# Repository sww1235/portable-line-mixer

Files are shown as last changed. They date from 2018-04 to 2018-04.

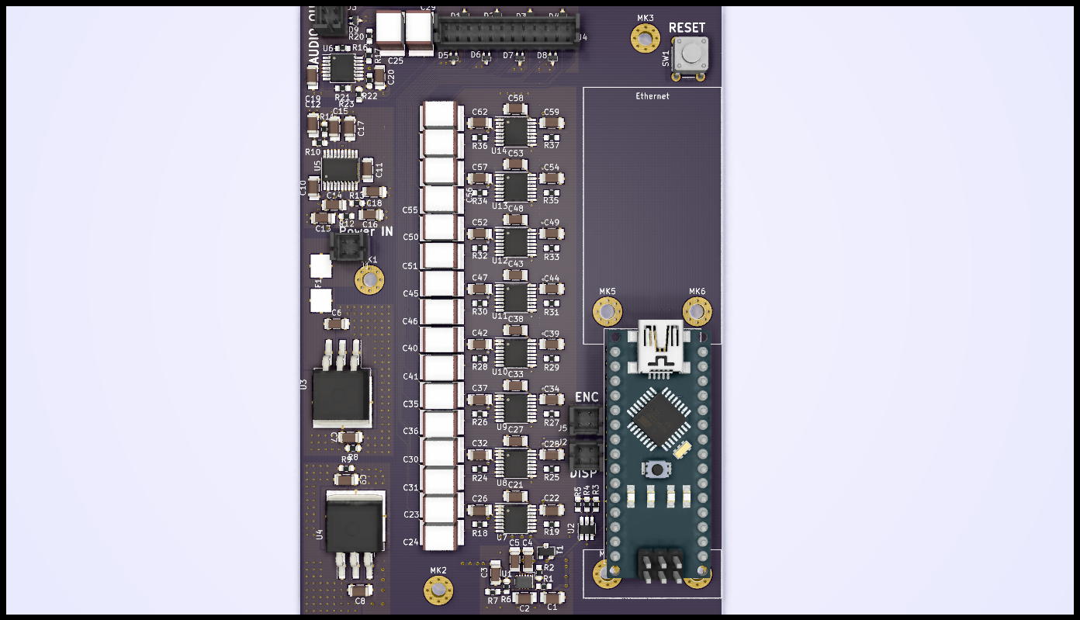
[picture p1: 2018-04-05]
portable-line-mixer.png

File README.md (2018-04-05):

# portable-line-mixer
A compact line level audio mixer.

Volume control via Digipots.

## TODO

-   Export BOM and price out parts
-   CODE

## Extra parts

-   772-E25-103RYY1 norcomp db25 IP67 connector male
-   772-E25-203RYY1 norcomp db25 IP67 connector female (for panelmount)
-   967-025-010R011 norcomp db25 IP67 backshell for cable
-   SFP6725 norcomp adhesive seal db25 size
-   967-025-CAP norcomp ip67 sealing cap
-   160-067-004R034 norcomp db25 hardware kit
-   767KS1(X) 0.084 \[2.1\] id/od sealed locking power plug switchcraft
-   L722AS 0.08 \[2.0\] id/od sealed locking power jack switchcraft (these sizes are compatible with high amperage version)
-   JCAP  power jack cover
-   35FM3AULS - Sealed locking 3.5mm panel mount jack switchcraft
-   35HDLBAU(S) 3.5mm sealed locking plug switchcraft (S=0.175 diameter cable, no S=0.29 diameter cable)
-   NE8FDX-P6-W IP rated ethercon connector Cat6A shielded neutrik
-   NE8MX6 Cat6A ethercon cable connector neutrik

## Max Power Consumption figures

| Component | Quantity | Current  | Voltage | Total Watts |
|:---|:---|:---|:---|:---|
| 4x Op Amp | 1 | 2.8mA | ±12V | 67.2mW |
| digipots  | 8 | 2uA, 5uA | +5VD, ±5VA | 0.48mW -> 0.5mW |
| microproc | 1 | 27mA | 5V | 135mW |
| Total | | | | 202.68mW |
| ref total | | | | 500mW |

## References / sources

### Code
-   <http://playground.arduino.cc/Main/RotaryEncoders#Example1>
-   <https://www.arduino.cc/en/Reference/Wire>
-   <http://gammon.com.au/interrupts>
-   <https://www.arduino.cc/en/Reference/AttachInterrupt>

### Physical Design
-   <https://m.reddit.com/r/arduino/comments/1tr7in/question_i_burned_out_this_small_smd_component_on/>
-   <https://www.arduino.cc/en/Hacking/PinMapping32u4>
-   <https://www.arduino.cc/en/Main/ArduinoBoardMicro>
-   <http://www.atmel.com/Images/Atmel-7766-8-bit-AVR-ATmega16U4-32U4_Datasheet.pdf>
-   <http://sound.whsites.net/articles/capacitors.htm>
-   <http://electronics.stackexchange.com/questions/210376/details-on-pcb-layout-for-microcontroller>
-   <http://electronics.stackexchange.com/questions/210580/pcb-microcontroller-layout-in-a-mixed-signal-system>
-   <http://electronics.stackexchange.com/questions/7535/what-precautions-should-i-take-when-mixing-analog-audio-and-digital-on-the-same>
-   <https://wiki.xtronics.com/index.php/Eeschema#Printing_to_a_web_viewable_file>
-   <http://www.all-electric.com/schematic/simp_mix.htm>
-   <http://sound.whsites.net/articles/audio-mixing.htm>
-   <http://www.hobbyprojects.com/A/mixers.html>
-   <https://www.maximintegrated.com/en/app-notes/index.mvp/id/1133>
-   <https://books.google.com/books?id=rZDbnQ0siCYC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>
-   <http://electronics.stackexchange.com/questions/5403/standard-pcb-trace-widths>
-   <http://electronics.stackexchange.com/questions/185212/i2c-pcb-layout-considerations>
-   <http://electronics.stackexchange.com/questions/39136/competing-pcb-crystal-layout-recommendations>
-   <http://electronics.stackexchange.com/questions/41851/how-critical-is-the-layout-of-usb-data-lines-how-does-my-layout-look>
-   <http://www.atmel.com/Images/Atmel-8128-Best-Practices-for-the-PCB-Layout-of-Oscillators_ApplicationNote_AVR186.pdf>
-   <http://www.ti.com/lit/an/scaa082/scaa082.pdf>
-   <http://electronics.stackexchange.com/questions/15135/decoupling-caps-pcb-layout/>
-   <http://electronics.stackexchange.com/questions/117817/learning-pcb-layout-strategy>
-   <http://electronics.stackexchange.com/questions/216410/pcb-layout-needs-improvement>
-   <http://electronics.stackexchange.com/questions/28251/rules-and-guidelines-for-drawing-good-schematics>
-   <http://electronics.stackexchange.com/questions/20180/pcb-layout-questions-for-mcu-breakout-board>
-   <http://electronics.stackexchange.com/questions/19688/is-it-normal-to-have-a-rats-nest-of-vcc-gnd-traces-under-an-ic>
-   <http://www.onmyphd.com/?p=pcb.design>
-   <http://www.ti.com/lit/an/scaa048/scaa048.pdf>
-   <http://www.hottconsultants.com/questions/mixed-signal_PCB_layout.html>
-   <http://www.hottconsultants.com/questions/supplying_power_to_a_mixed-signal_PCB.html>
-   <http://www.analog.com/en/analog-dialogue/articles/staying-well-grounded.html>

### Microphone references for future iterations of design
-   <http://electronics.stackexchange.com/questions/141499/5v-electret-microphone-to-pc-mute-switch-pop-help>

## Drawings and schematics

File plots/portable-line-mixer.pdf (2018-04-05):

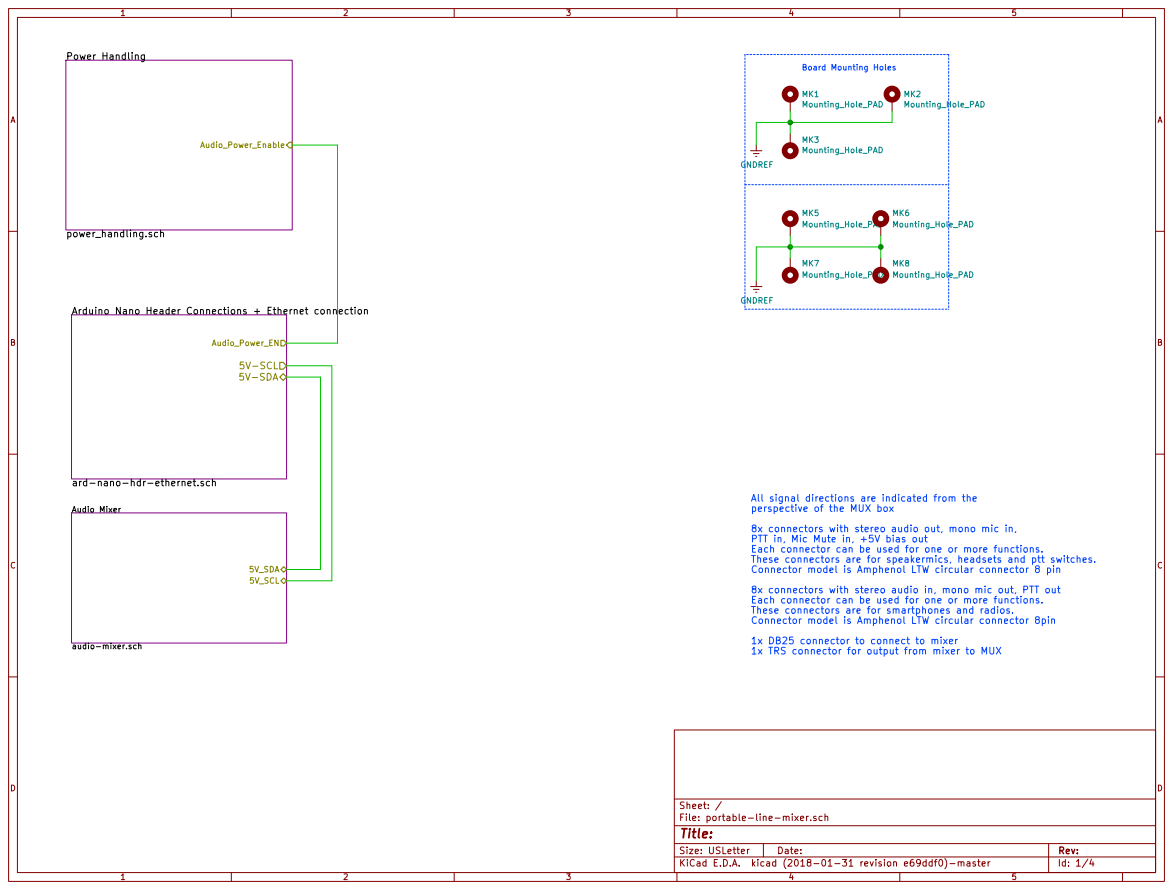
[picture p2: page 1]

Audio_Power_Enable Arduino Nano Header Connections + Ethernet connection

ard-nano-hdr-ethernet.sch

perspective of the MUX box
8x connectors with stereo audio out, mono mic in,
PTT in, Mic Mute in, +5V bias out Each connector can be used for one or more functions. These connectors are for speakermics, headsets and ptt switches.

Connector model is Amphenol LTW circular connector 8 pin
8x connectors with stereo audio in, mono mic out, PTT out Each connector can be used for one or more functions. These connectors are for smartphones and radios.

Connector model is Amphenol LTW circular connector 8pin
1x DB25 connector to connect to mixer 1x TRS connector for output from mixer to MUX

File: portable-line-mixer.sch Sheet: /

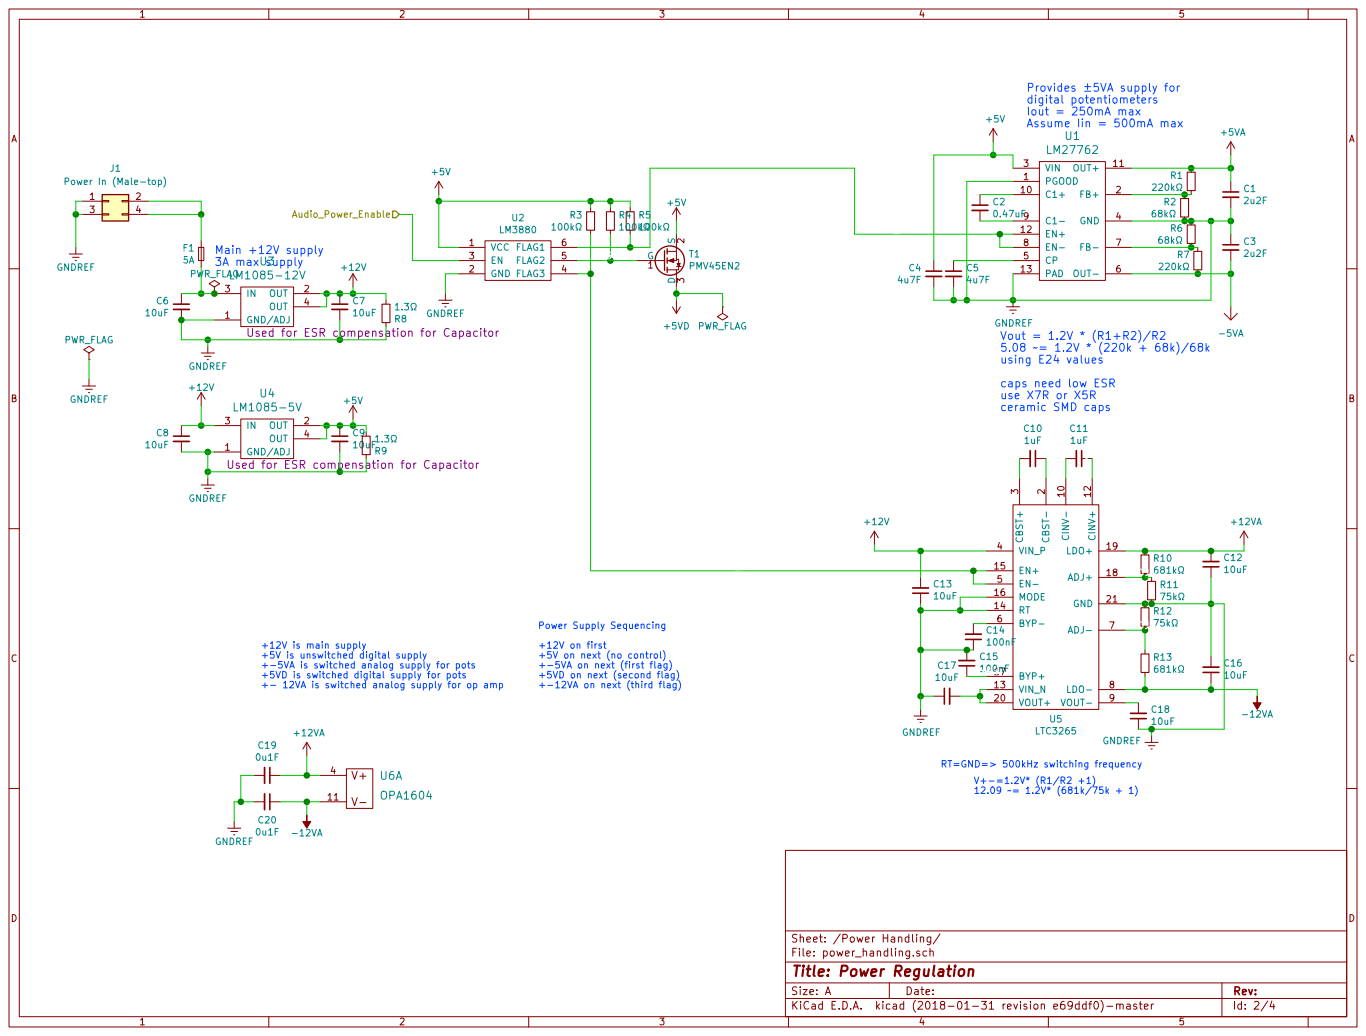
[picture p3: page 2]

Iout = 250mA max Assume Iin = 500mA max R8
LM3880 Power Supply Sequencing +12V on first +5V on next (no control)

3 T1PMV45EN2 CINV- 10 CINV+ 12 VIN_N 13 RT 14 EN+ 15 MODE 16 BYP+ 17 ADJ+ 18

Vout = 1.2V * (R1+R2)/R2
using E24 values
caps need low ESR
use X7R or X5R
ceramic SMD caps

+12V is main supply
+5V is unswitched digital supply
+-5VA is switched analog supply for pots
+5VD is switched digital supply for pots
+- 12VA is switched analog supply for op amp

+-5VA on next (first flag)
+5VD on next (second flag)
+-12VA on next (third flag)

Sheet: /Power Handling/
File: power_handling.sch
Id: 2/4 Title: Power Regulation

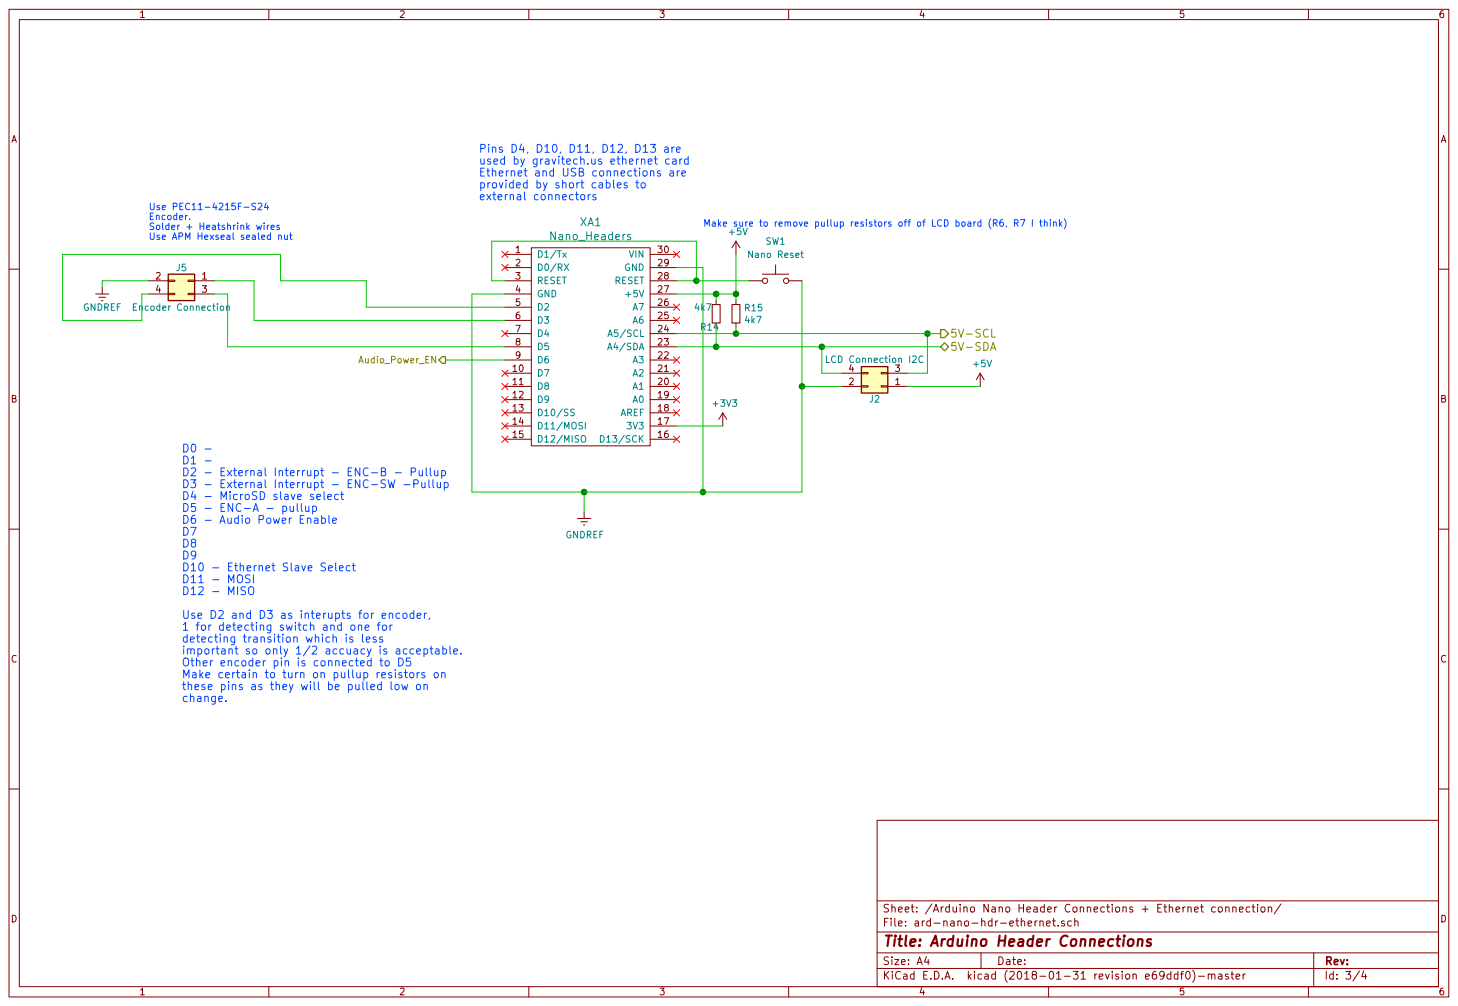
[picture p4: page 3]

+3V3 Pins D4, D10, D11, D12, D13 are
used by gravitech.us ethernet card
Ethernet and USB connections are

Nano_RST D0 - D1 - D2 - External Interrupt - ENC-B - Pullup

D3 - External Interrupt - ENC-SW -Pullup
D4 - MicroSD slave select
D5 - ENC-A - pullup D6 - Audio Power Enable D7 D8 D9 D10 - Ethernet Slave Select

D11 - MOSI
D12 - MISO
Use D2 and D3 as interupts for encoder,
1 for detecting switch and one for
detecting transition which is less
important so only 1/2 accuacy is acceptable.
Other encoder pin is connected to D5
Make certain to turn on pullup resistors on
these pins as they will be pulled low on

File: ard-nano-hdr-ethernet.sch Sheet: /Arduino Nano Header Connections + Ethernet connection/
Id: 3/4 Title: Arduino Header Connections

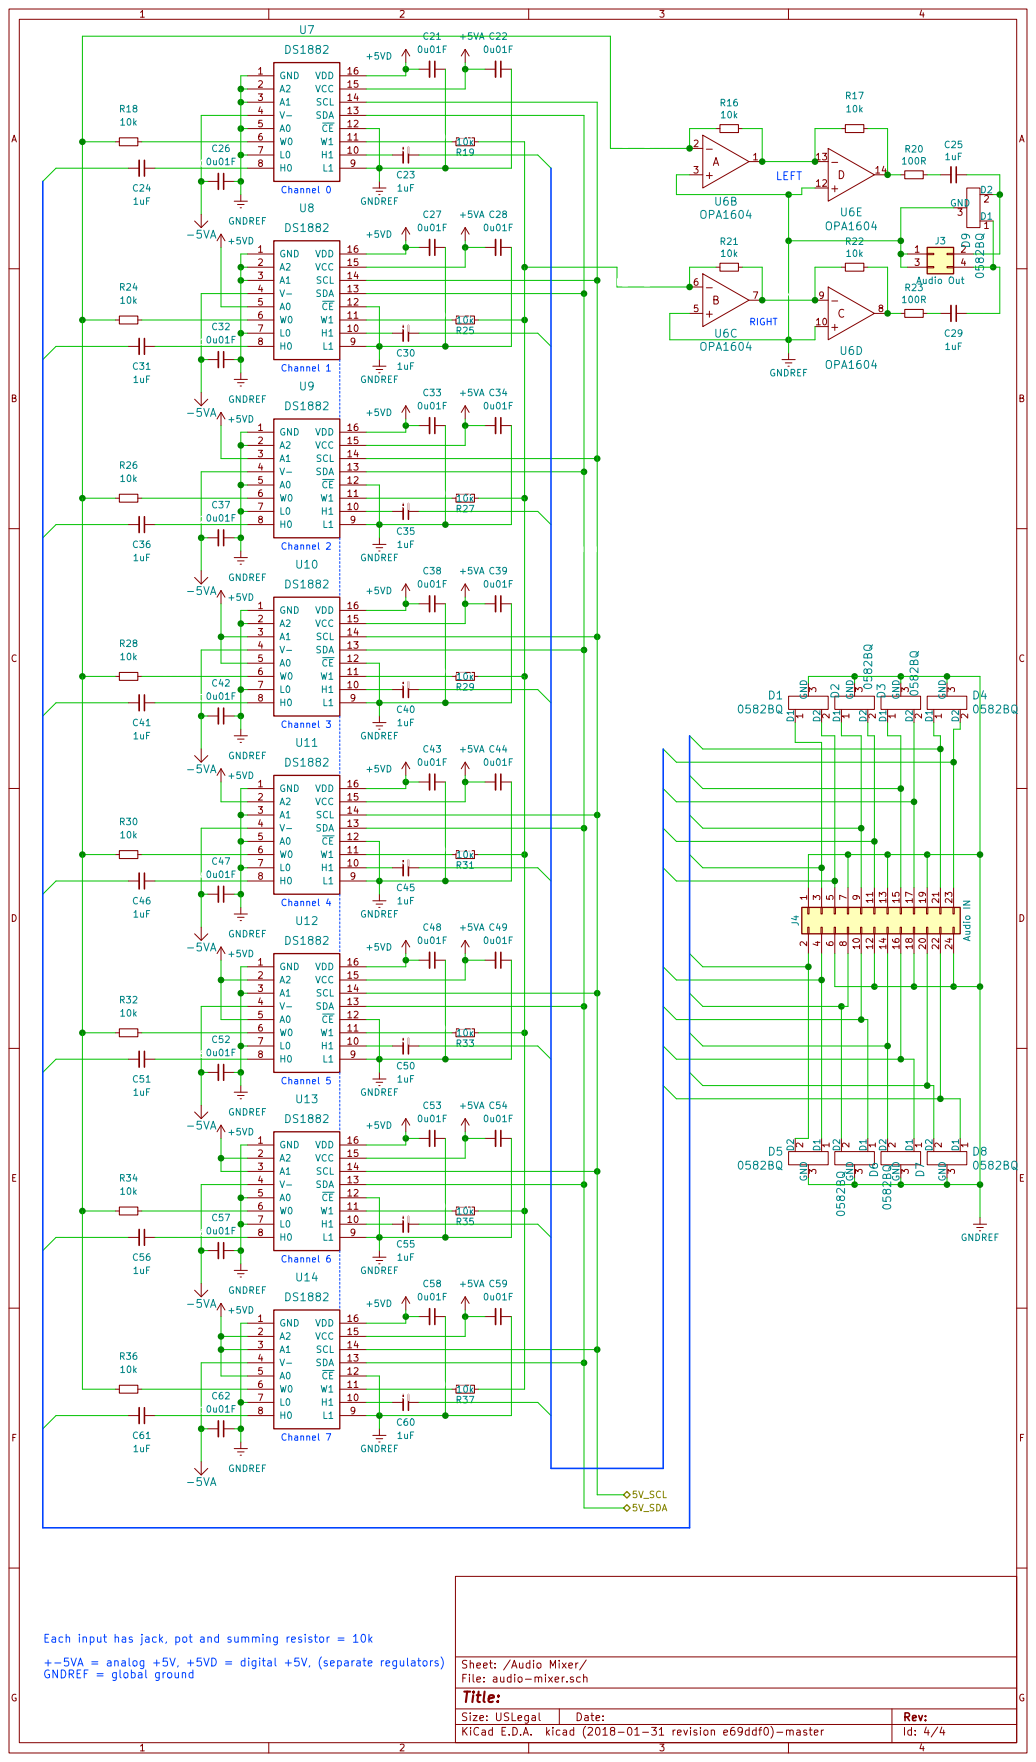
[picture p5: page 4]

F-LIN-0 F-LIN-1 F-LIN-2 F-LIN-3 F-LIN-4 F-LIN-5 F-LIN-6 F-LIN-7

ROUT-0 ROUT-1 ROUT-2 ROUT-3 ROUT-4 ROUT-5 ROUT-6 ROUT-7
F-RIN-0 F-RIN-1 F-RIN-2 F-RIN-3 F-RIN-4 F-RIN-5 F-RIN-6 F-RIN-7

FG Date: KiCad E.D.A. kicad (2018-01-31 revision e69ddf0)-master

Id: 4/4 Title: File: audio-mixer.sch Sheet: /Audio Mixer/ Each input has jack, pot and summing resistor = 10k
+-5VA = analog +5V, +5VD = digital +5V, (separate regulators)
GNDREF = global ground

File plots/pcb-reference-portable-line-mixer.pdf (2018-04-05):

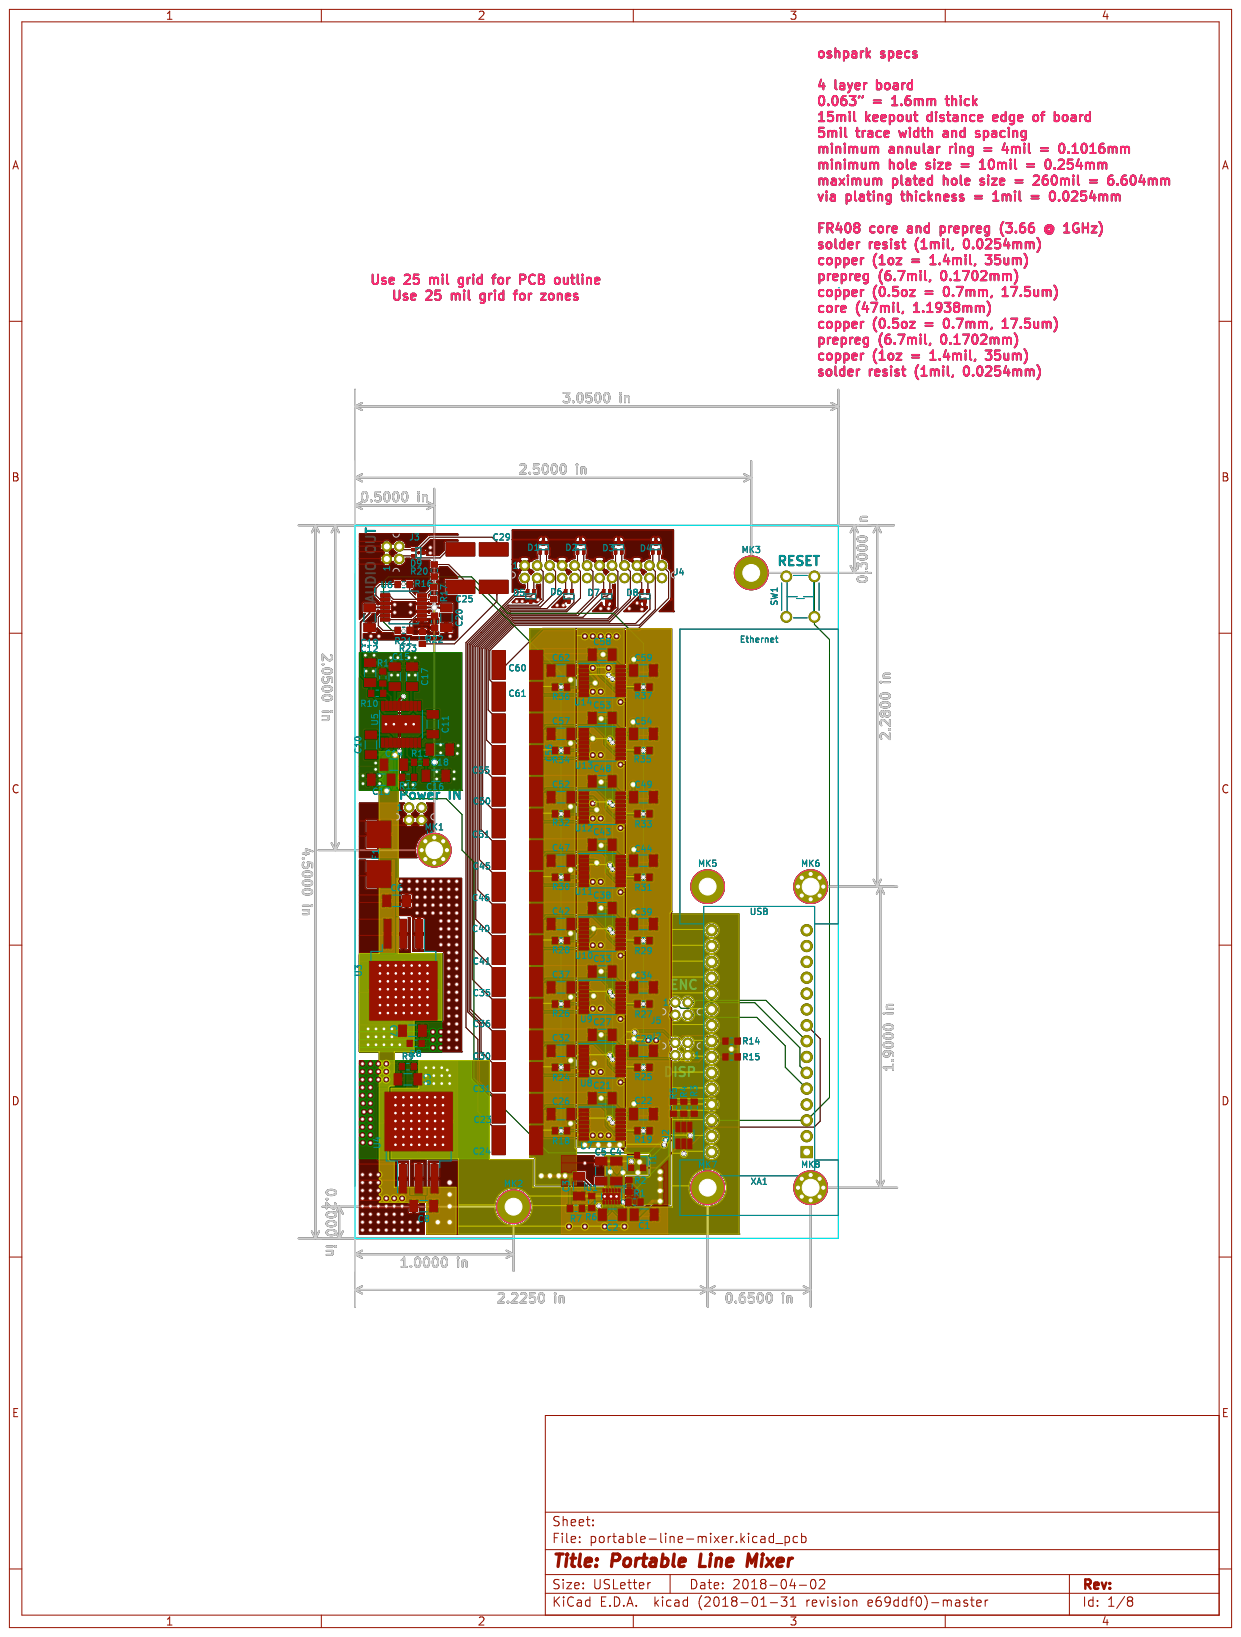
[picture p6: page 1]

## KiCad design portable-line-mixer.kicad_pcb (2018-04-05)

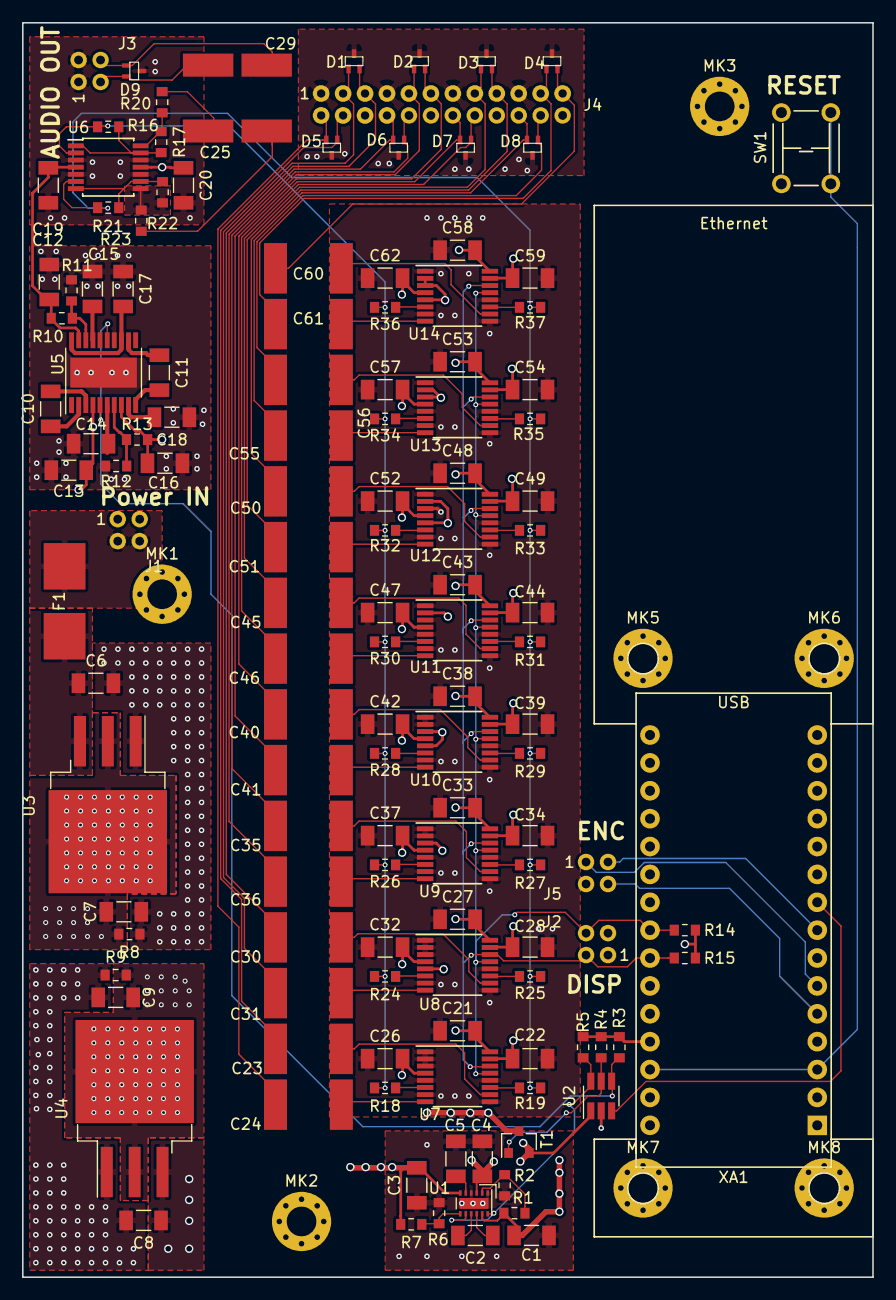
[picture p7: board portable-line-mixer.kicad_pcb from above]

Board: 4 copper layers, 77.5 x 114.3 mm, 138 parts (0 on the bottom side), 93 nets.

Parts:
C1, C3: 2u2F; C_1206_3216Metric_Pad1.24x1.80mm_HandSolder
C2: 0.47uF; C_1206_3216Metric_Pad1.24x1.80mm_HandSolder
C4, C5: 4u7F; C_1206_3216Metric_Pad1.24x1.80mm_HandSolder
C6, C7, C8, C9, C12, C13, C16, C17, C18: 10uF; C_1206_3216Metric_Pad1.24x1.80mm_HandSolder
C10, C11: 1uF; C_1206_3216Metric_Pad1.24x1.80mm_HandSolder
C14, C15: 100nF; C_1206_3216Metric_Pad1.24x1.80mm_HandSolder
C19, C20: 0u1F; C_1206_3216Metric_Pad1.24x1.80mm_HandSolder
C21, C22, C26, C27, C28, C32, C33, C34, C37, C38, C39, C42, C43, C44, C47, C48, C49, C52, C53, C54, C57, C58, C59, C62: 0u01F; C_1206_3216Metric_Pad1.24x1.80mm_HandSolder
C23, C24, C25, C29, C30, C31, C35, C36, C40, C41, C45, C46, C50, C51, C55, C56, C60, C61: 1uF; Kemet_CAP_2220_5750Metric_D
D1, D2, D3, D4, D5, D6, D7, D8, D9: 0582BQ; SC-75_3L
F1: 5A; NANO-0154-OMNI-BLOK-Fuse-Holder
J1: Power In (Male-top); DF11-4DP-2DSA
J2: LCD Connection I2C; DF11-4DP-2DSA
J3: Audio Out; DF11-4DP-2DSA
J4: Audio IN; DF11-24DP-2DSA
J5: Encoder Connection; DF11-4DP-2DSA
MK1, MK2, MK3, MK5, MK6, MK7, MK8: Mounting_Hole_PAD; MountingHole_2.7mm_M2.5_Pad_Via
R1, R7: 220kΩ; R_0603_1608Metric_Pad0.84x1.00mm_HandSolder
R2, R6: 68kΩ; R_0603_1608Metric_Pad0.84x1.00mm_HandSolder
R3, R4, R5: 100kΩ; R_0603_1608Metric_Pad0.84x1.00mm_HandSolder
R8, R9: 1.3Ω; R_0603_1608Metric_Pad0.84x1.00mm_HandSolder
R10, R13: 681kΩ; R_0603_1608Metric_Pad0.84x1.00mm_HandSolder
R11, R12: 75kΩ; R_0603_1608Metric_Pad0.84x1.00mm_HandSolder
R14, R15: 4k7; R_0603_1608Metric_Pad0.84x1.00mm_HandSolder
R16, R17, R18, R19, R21, R22, R24, R25, R26, R27, R28, R29, R30, R31, R32, R33, R34, R35, R36, R37: 10k; R_0603_1608Metric_Pad0.84x1.00mm_HandSolder
R20, R23: 100R; R_0603_1608Metric_Pad0.84x1.00mm_HandSolder
SW1: Nano Reset; TL1105
T1: PMV45EN2; SOT-23
U1: LM27762; WSON-12-1EP_3x2mm_P0.5mm
U2: LM3880; SOT-23-6_Handsoldering
U3: LM1085-12V; TO-263-3_TabPin4
U4: LM1085-5V; TO-263-3_TabPin4
U5: LTC3265; TSSOP-20-1EP_4.4x6.5mm_P0.65mm_EP2.75x6.07mm-LTC3265
U6: OPA1604; TSSOP-14_4.4x5mm_P0.65mm
U7, U8, U9, U10, U11, U12, U13, U14: DS1882; TSSOP-16_4.4x5mm_P0.65mm
XA1: Nano_Headers; Nano-Header-Ethernet-4NANO

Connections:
+5V: C4.1, C9.1, J2.1, R3.1, R4.1, R5.1, R9.2, R14.1, R15.1, T1.2, U1.3, U2.1, U4.2, U4.4, XA1.27
+5VA: C1.1, C22.2, C28.2, C34.2, C39.2, C44.2, C49.2, C54.2, C59.2, R1.1, U1.11, U7.15, U8.15, U9.15, U10.15, U11.15, U12.15, U13.15, U14.15
+5VD: C21.2, C27.2, C33.2, C38.2, C43.2, C48.2, C53.2, C58.2, T1.3, U7.16, U8.5, U8.16, U9.3, U9.16, U10.3, U10.5, U10.16, U11.2, U11.16, U12.2, U12.5, U12.16, U13.2, U13.3, U13.16, U14.2, U14.3, U14.5, U14.16
+12V: C7.1, C8.1, C13.2, R8.2, U3.2, U3.4, U4.3, U5.4
+12VA: C12.2, C19.1, R10.1, U5.19, U6.4
-5VA: C3.2, C26.2, C32.2, C37.2, C42.2, C47.2, C52.2, C57.2, C62.2, R7.2, U1.6, U7.4, U8.4, U9.4, U10.4, U11.4, U12.4, U13.4, U14.4
-12VA: C16.1, C20.1, R13.2, U5.8, U6.11
/Arduino Nano Header Connections + Ethernet connection/5V-SCL: J2.3, R15.2, U7.14, U8.14, U9.14, U10.14, U11.14, U12.14, U13.14, U14.14, XA1.24
/Arduino Nano Header Connections + Ethernet connection/5V-SDA: J2.4, R14.2, U7.13, U8.13, U9.13, U10.13, U11.13, U12.13, U13.13, U14.13, XA1.23
/Arduino Nano Header Connections + Ethernet connection/Audio_Power_EN: U2.3, XA1.9
/Arduino Nano Header Connections + Ethernet connection/ENC-1: J5.1, XA1.6
/Arduino Nano Header Connections + Ethernet connection/ENC-A: J5.3, XA1.8
/Arduino Nano Header Connections + Ethernet connection/ENC-B: J5.4, XA1.5
/Arduino Nano Header Connections + Ethernet connection/Nano_RST: SW1.1, XA1.3, XA1.28
/Audio Mixer/F-LIN-0: C24.1, U7.8
/Audio Mixer/F-LIN-1: C31.1, U8.8
/Audio Mixer/F-LIN-2: C36.1, U9.8
/Audio Mixer/F-LIN-3: C41.1, U10.8
/Audio Mixer/F-LIN-4: C46.1, U11.8
/Audio Mixer/F-LIN-5: C51.1, U12.8
/Audio Mixer/F-LIN-6: C56.1, U13.8
/Audio Mixer/F-LIN-7: C61.1, U14.8
/Audio Mixer/F-RIN-0: C23.2, U7.10
/Audio Mixer/F-RIN-1: C30.2, U8.10
/Audio Mixer/F-RIN-2: C35.2, U9.10
/Audio Mixer/F-RIN-3: C40.2, U10.10
/Audio Mixer/F-RIN-4: C45.2, U11.10
/Audio Mixer/F-RIN-5: C50.2, U12.10
/Audio Mixer/F-RIN-6: C55.2, U13.10
/Audio Mixer/F-RIN-7: C60.2, U14.10
/Audio Mixer/L-IN0: C24.2, D5.2, J4.2
/Audio Mixer/L-IN1: C31.2, D1.1, J4.3
/Audio Mixer/L-IN2: C36.2, D6.2, J4.8
/Audio Mixer/L-IN3: C41.2, D2.1, J4.9
/Audio Mixer/L-IN4: C46.2, D7.2, J4.14
/Audio Mixer/L-IN5: C51.2, D3.1, J4.15
/Audio Mixer/L-IN6: C56.2, D8.2, J4.20
/Audio Mixer/L-IN7: C61.2, D4.1, J4.21
/Audio Mixer/LINV: R16.1, R17.2, U6.1, U6.13
/Audio Mixer/LOUT: C25.1, D9.2, J3.2
/Audio Mixer/LOUT-0: R18.1, U7.6
/Audio Mixer/LOUT-1: R24.1, U8.6
/Audio Mixer/LOUT-2: R26.1, U9.6
/Audio Mixer/LOUT-3: R28.1, U10.6
/Audio Mixer/LOUT-4: R30.1, U11.6
/Audio Mixer/LOUT-5: R32.1, U12.6
/Audio Mixer/LOUT-6: R34.1, U13.6
/Audio Mixer/LOUT-7: R36.1, U14.6
/Audio Mixer/L_MIX_BUS: R16.2, R18.2, R24.2, R26.2, R28.2, R30.2, R32.2, R34.2, R36.2, U6.2
/Audio Mixer/R-IN0: C23.1, D5.1, J4.4
/Audio Mixer/R-IN1: C30.1, D1.2, J4.5
/Audio Mixer/R-IN2: C35.1, D6.1, J4.10
/Audio Mixer/R-IN3: C40.1, D2.2, J4.11
/Audio Mixer/R-IN4: C45.1, D7.1, J4.16
/Audio Mixer/R-IN5: C50.1, D3.2, J4.17
/Audio Mixer/R-IN6: C55.1, D8.1, J4.22
/Audio Mixer/R-IN7: C60.1, D4.2, J4.23
/Audio Mixer/RINV: R21.1, R22.2, U6.7, U6.9
/Audio Mixer/ROUT: C29.1, D9.1, J3.4
/Audio Mixer/ROUT-0: R19.2, U7.11
/Audio Mixer/ROUT-1: R25.2, U8.11
/Audio Mixer/ROUT-2: R27.2, U9.11
/Audio Mixer/ROUT-3: R29.2, U10.11
/Audio Mixer/ROUT-4: R31.2, U11.11
/Audio Mixer/ROUT-5: R33.2, U12.11
/Audio Mixer/ROUT-6: R35.2, U13.11
/Audio Mixer/ROUT-7: R37.2, U14.11
/Audio Mixer/R_MIX_BUS: R19.1, R21.2, R25.1, R27.1, R29.1, R31.1, R33.1, R35.1, R37.1, U6.6
/Power Handling/+5VD_EN: R4.2, T1.1, U2.5
/Power Handling/+12V-F: C6.1, F1.2, U3.3
/Power Handling/ADJ+: R10.2, R11.1, U5.18
/Power Handling/ADJ-: R12.2, R13.1, U5.7
/Power Handling/BYP+: C15.1, U5.17
/Power Handling/BYP-: C14.2, U5.6
/Power Handling/CBST+: C10.2, U5.3
/Power Handling/CBST-: C10.1, U5.2
/Power Handling/CINV+: C11.2, U5.10
/Power Handling/CINV-: C11.1, U5.12
/Power Handling/VIN+: F1.1, J1.2, J1.4
/Power Handling/VOUT+: C17.2, U5.13, U5.20
/Power Handling/VOUT-: C18.2, U5.9
/Power Handling/±5VA_EN: R5.2, U1.8, U1.12, U2.6
/Power Handling/±12VA_EN: R3.2, U2.4, U5.5, U5.15
GNDREF: C1.2, C3.1, C4.2, C5.2, C6.2, C7.2, C8.2, C9.2, C12.1, C13.1, C14.1, C15.2, C16.2, C17.1, C18.1, C19.2, C20.2, C21.1, C22.1, C26.1, C27.1, C28.1, C32.1, C33.1, C34.1, C37.1, C38.1, C39.1, C42.1, C43.1, C44.1, C47.1, C48.1, C49.1, C52.1, C53.1, C54.1, C57.1, C58.1, C59.1, C62.1, D1.3, D2.3, D3.3, D4.3, D5.3, D6.3, D7.3, D8.3, D9.3, J1.1, J1.3, J2.2, J3.1, J3.3, J4.1, J4.6, J4.7, J4.12, J4.13, J4.18, J4.19, J4.24, J5.2, MK1.1, MK2.1, MK3.1, MK5.1, MK6.1, MK7.1, MK8.1, R2.2, R6.1, R8.1, R9.1, R11.2, R12.1, SW1.2, U1.1, U1.4, U1.13, U2.2, U3.1, U4.1, U5.14, U5.16, U5.21, U6.3, U6.5, U6.10, U6.12, U7.1, U7.2, U7.3, U7.5, U7.7, U7.9, U7.12, U8.1, U8.2, U8.3, U8.7, U8.9, U8.12, U9.1, U9.2, U9.5, U9.7, U9.9, U9.12, U10.1, U10.2, U10.7, U10.9, U10.12, U11.1, U11.3, U11.5, U11.7, U11.9, U11.12, U12.1, U12.3, U12.7, U12.9, U12.12, U13.1, U13.5, U13.7, U13.9, U13.12, U14.1, U14.7, U14.9, U14.12, XA1.4, XA1.29
unnamed: C2.1, U1.10
unnamed: C2.2, U1.9
unnamed: C5.1, U1.5
unnamed: C25.2, R20.1
unnamed: C29.2, R23.1
unnamed: R1.2, R2.1, U1.2
unnamed: R6.2, R7.1, U1.7
unnamed: R17.1, R20.2, U6.14
unnamed: R22.1, R23.2, U6.8

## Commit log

2016-10-22 almost done with first iteration of design
    [microprocessor.sch, portable-line-mixer.kicad_pcb, portable-line-mixer.sch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]
2016-10-22 finished with first draft of schematic
    [microprocessor.sch, portable-line-mixer.sch, power-subsheet.sch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]
2016-10-30 finalized schematic, finishing footprint assignment, starting pcb layout
    [microprocessor.sch, portable-line-mixer.kicad_pcb, portable-line-mixer.sch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]
2016-10-30 replacing audio jack footprints
    [portable-line-mixer.kicad_pcb, portable-line-mixer.sch, stereo-input.sch]
2016-10-30 before initial DRC
    [microprocessor.sch, portable-line-mixer.kicad_pcb, portable-line-mixer.sch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]
2016-10-30 after DRC and fixes
    [portable-line-mixer.kicad_pcb]
2016-11-08 added power consumption figures
2017-03-31 updating to new kicad version
    [microprocessor.sch]
2017-03-31 adding library cache and recovery after new kicad version
2017-03-31 library updates for new kicad version 4.0.6
    [portable-line-mixer.sch, power-subsheet.sch, stereo-input.sch]
2017-03-31 Added USBC switchover to TODO list
2017-12-27 Updated to new file formats
    [microprocessor.sch, portable-line-mixer.sch, power-subsheet.sch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]
2018-04-01 Reworking with new power supply and layout
    also changing to kicad 5 style library layout and management
    [ard-nano-hdr-ethernet.sch, audio-mixer.sch, microprocessor.sch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]
2018-04-02 Updated Schematics
    - added ethernet
    - swapped to using prebuilt nano
    - swapped to using db25 connector
    - swapped other connectors
    - added connectors for an LCD screen
    [ard-nano-hdr-ethernet.sch, audio-mixer.sch, portable-line-mixer.sch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]
2018-04-02 Added net labels and started schematic
    [ard-nano-hdr-ethernet.sch, audio-mixer.sch, portable-line-mixer.sch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]
2018-04-02 Removing old files from old design
    [portable-line-mixer-bk.kicad_pcb, portable-line-mixer-bk.sch]
2018-04-02 Swapped encoder for connector
    [ard-nano-hdr-ethernet.sch, portable-line-mixer.kicad_pcb, power_handling.sch]
2018-04-03 Portable Line Mixer done
    [ard-nano-hdr-ethernet.sch, portable-line-mixer.kicad_pcb, portable-line-mixer.sch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]
2018-04-03 Fixed pad connection on ±12V regulator
    [portable-line-mixer.kicad_pcb]
2018-04-05 Swapped right angle reset switch for straight
    [ard-nano-hdr-ethernet.sch, portable-line-mixer.kicad_pcb]
2018-04-05 Updated power table
